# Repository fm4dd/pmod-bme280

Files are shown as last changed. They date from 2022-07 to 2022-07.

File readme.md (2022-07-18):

## BME280 PMOD

### Description

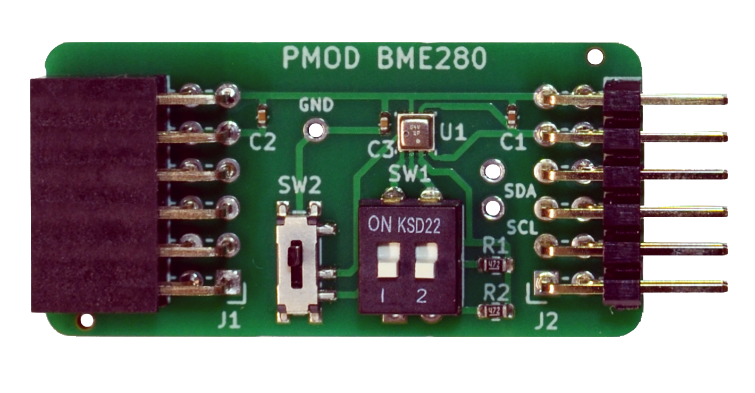
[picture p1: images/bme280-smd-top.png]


This PMOD connects the Bosch BME280 humidity, pressure and temperature sensor over I2C, using Digilent's PMOD interface type 6A per PMOD specification v1.3.1. The PMOD module can be chained to add additional I2C devices to the bus. The I2C pull-up resistors can be enabled/disabled using DIP switches, and switch 2 toggles the sensors I2C address between 0x76 and 0x77.

http://fpga.fm4dd.com/

This design is registered under the OSHWA Open Source Hardware Self-Certification:



### Schematic
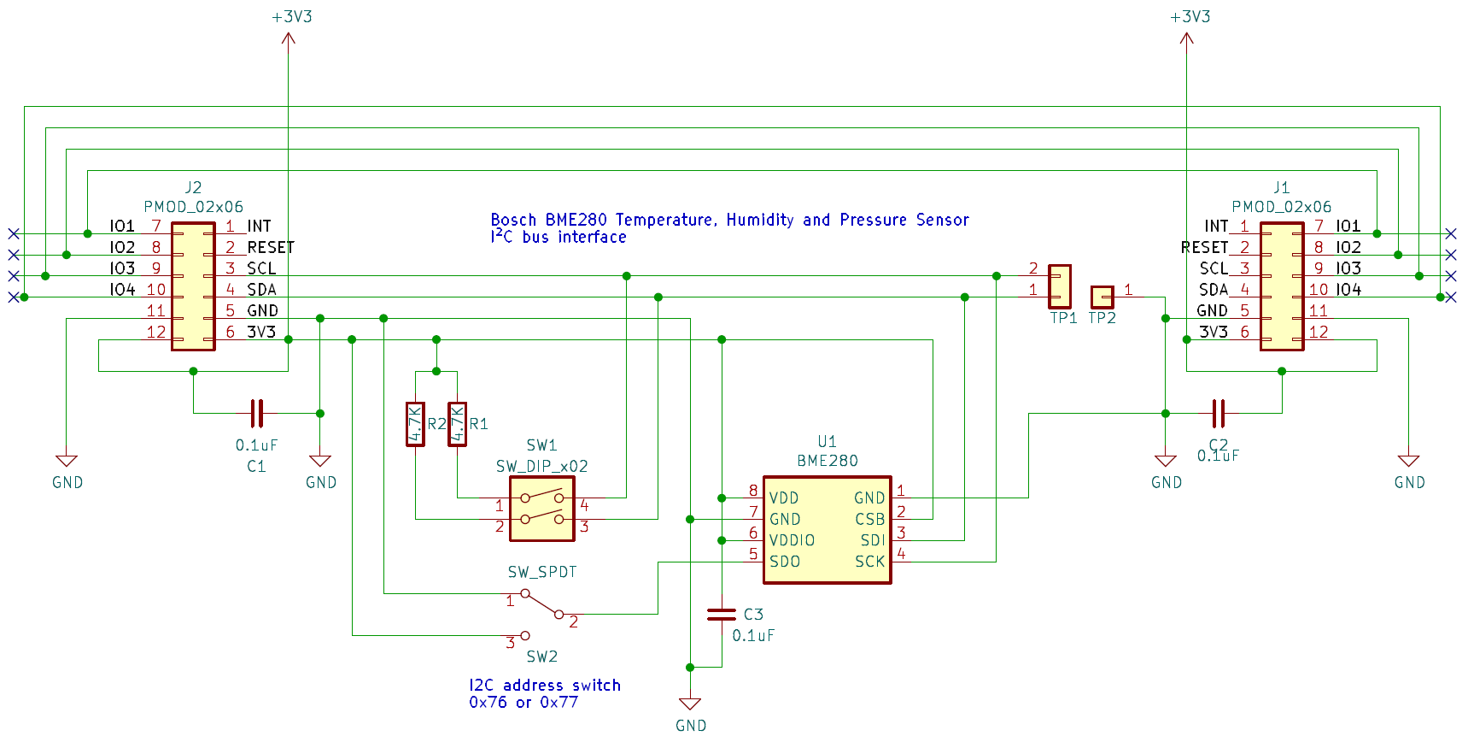
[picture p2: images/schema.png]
BME280 PMOD Schematics


### PCB Gerber
[BME280 PMOD Gerber V1.0](20220624-bme280-gerber-v10.zip)

### PMOD Interface Pin Assignments

Pin  |	Label |	Description   | Pin  |	Label |	Description
-----|--------|---------------|------|--------|---------------
1    |	-     |	Not connected |7     | -      | Not connected
2    |	-     |	Not connected |8     | -      | Not connected
3    |	SCL   |	I2C clock     |9     | -      | Not connected
4    |  SDA   | I2C data      |10    | -      | Not connected
5    |  GND   | ground        |11    | GND    | ground
6    |  3V3   | 3.3V          |12    | 3V3    | 3.3V

All pins are passed through from connector J1 to J2, allowing to chain multiple type 6/6A PMODs.

### Example Code

#### Linux

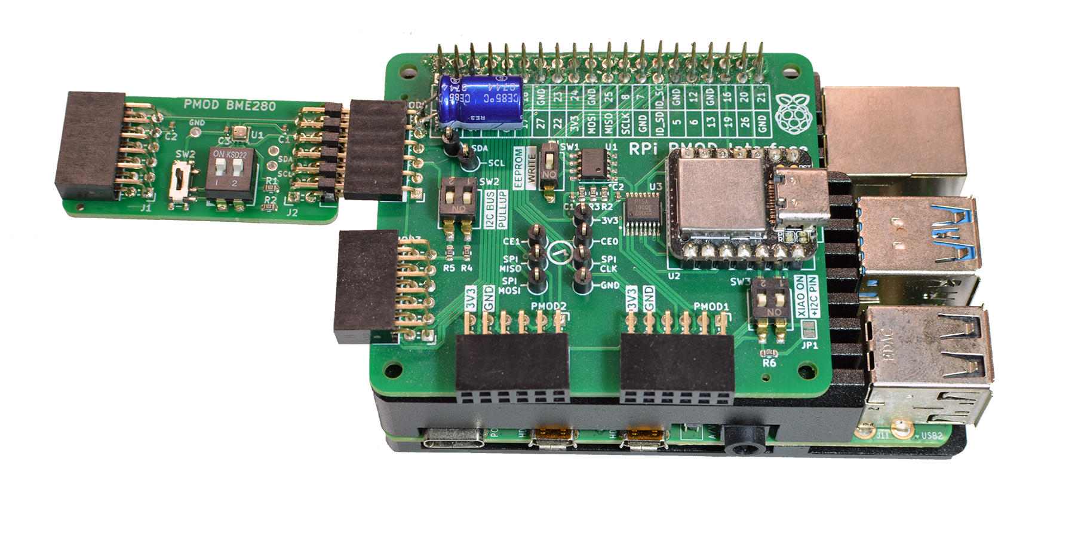
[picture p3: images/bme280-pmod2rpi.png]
BME280 PMOD on PMOD2RPI


Above shows the BME280 PMOD, connected to a [PMOD2RPI](https://github.com/fm4dd/pmod2rpi) interface board. When connected through the PMOD4 connector, the module can be controlled from the Raspberry Pi 4 Linux, running the [pi-bme280](https://github.com/fm4dd/pi-bme280) control program.

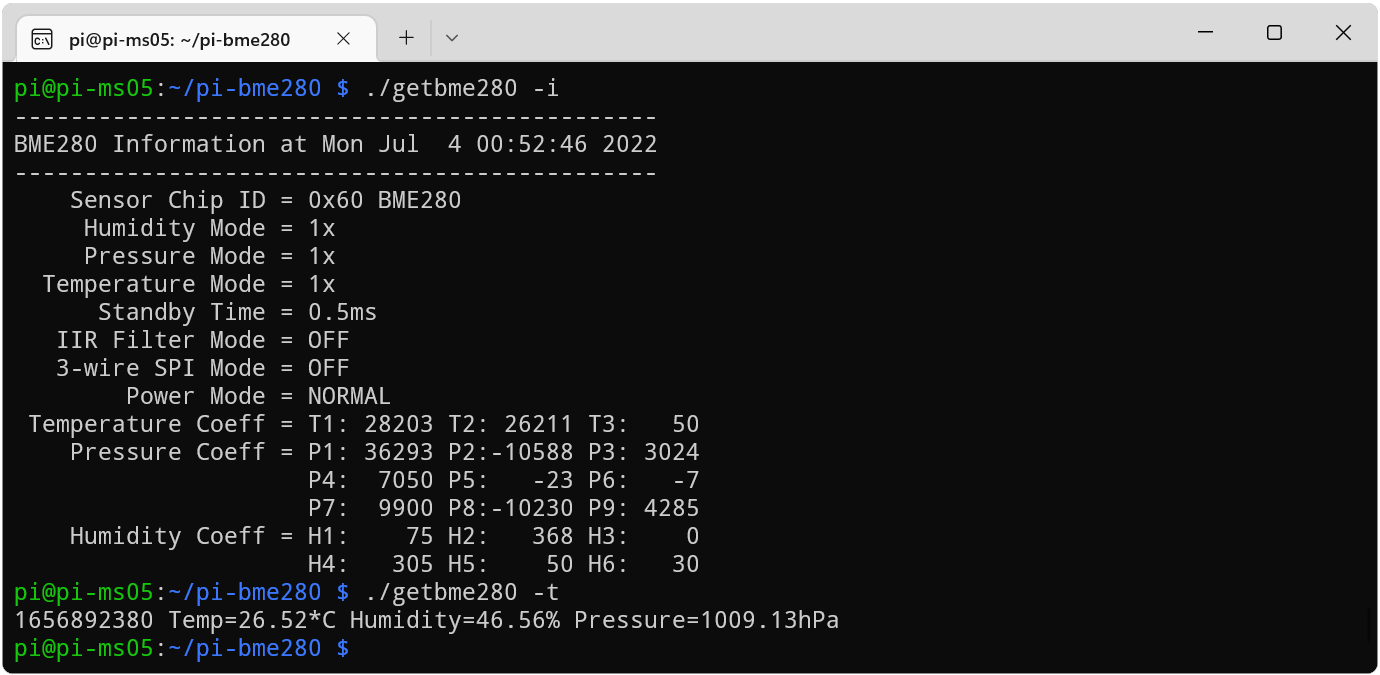
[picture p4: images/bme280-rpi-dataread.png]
BME280 PMOD Data Read


#### Arduino

Without any changes, we can run BME280 sample code such as the [BMx280_I2C](https://bitbucket.org/christandlg/bmx280mi/src/master/examples/BMx280_I2C/BMx280_I2C.ino) example program from the BMx280MI library provided by Gregor Christandl. The BME280 PMOD module is connected to the [PMOD2RPI](https://github.com/fm4dd/pmod2rpi) interface board. On port PMOD1, the module communicates over I2C with the onboard Seeedstudio XIAO Cortex-M0 MCU.

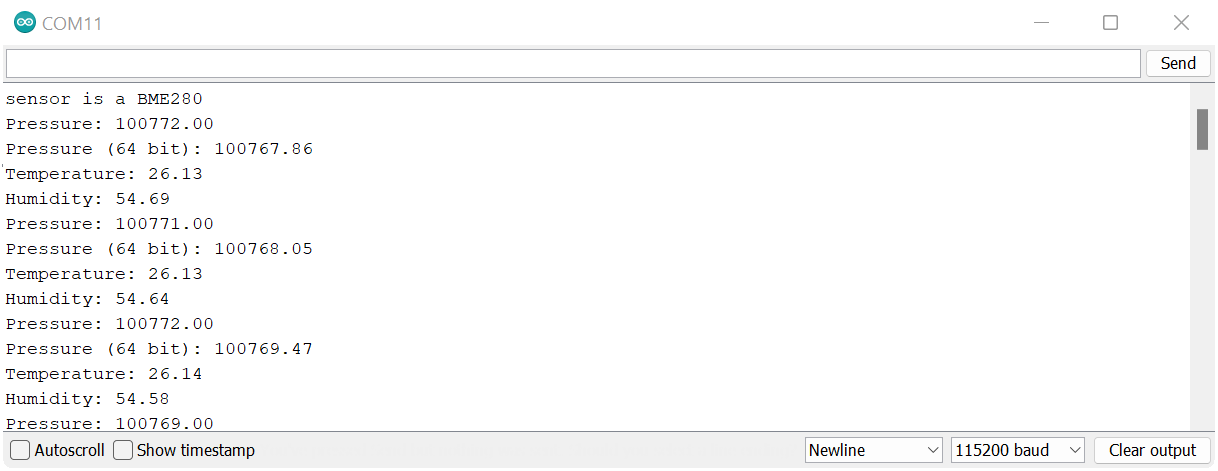
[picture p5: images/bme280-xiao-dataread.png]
BME280 PMOD Data Read


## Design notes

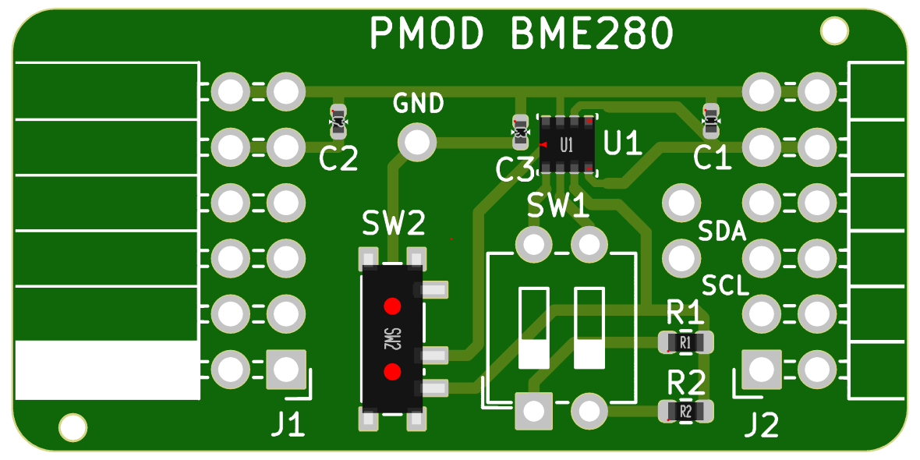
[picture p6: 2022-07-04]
images/bme280-smd-v10.png

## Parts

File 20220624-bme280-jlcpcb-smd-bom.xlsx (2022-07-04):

Comment | Designator | Footprint | LCSC Part #（optional）
BME280 | U1 | LGA-8_2.5x2.5x0.65P | C92489
SPDT | SW2 | Switch_SMD:SW_12mm | C397350
4.7K | R2,R1 | Resistor_SMD:R_0603_1608Metric
100nF | C3,C2,C1 | Capacitor_SMD:C_0402Metric

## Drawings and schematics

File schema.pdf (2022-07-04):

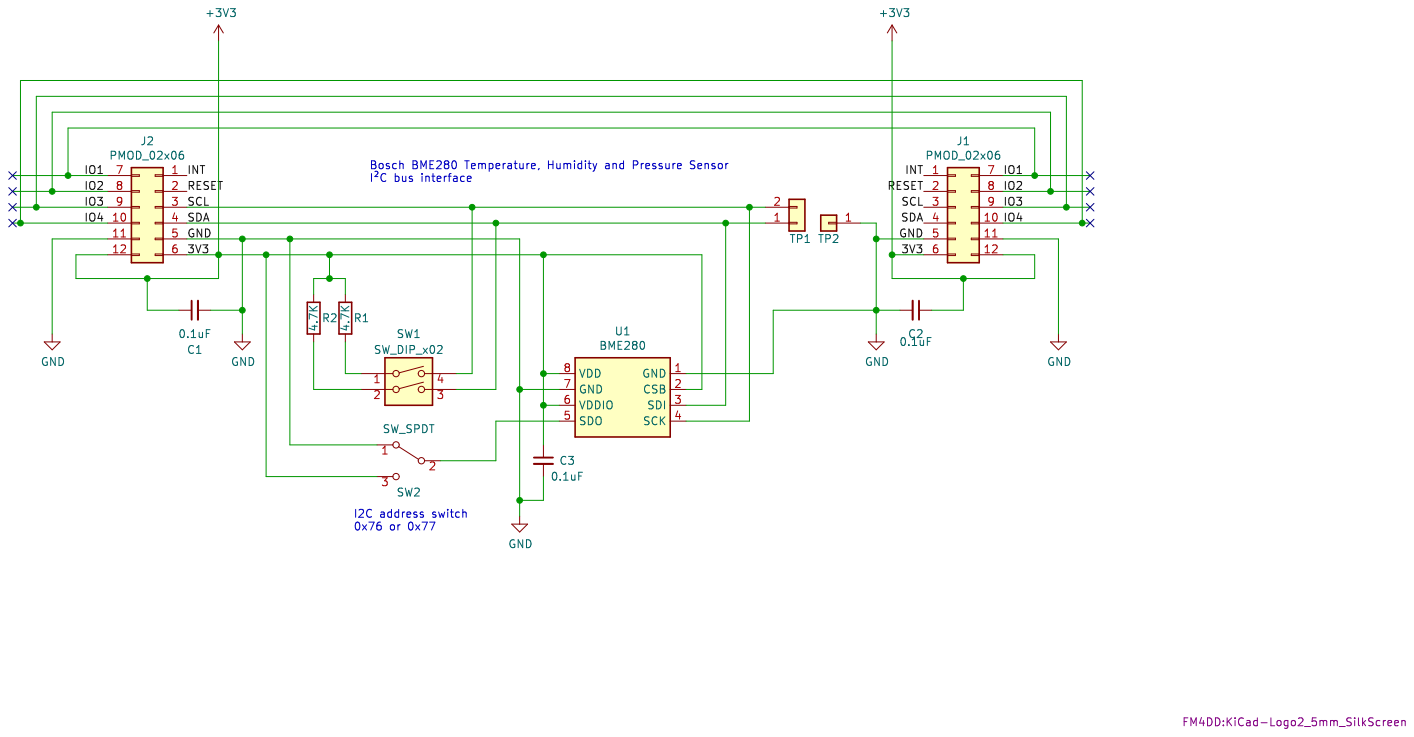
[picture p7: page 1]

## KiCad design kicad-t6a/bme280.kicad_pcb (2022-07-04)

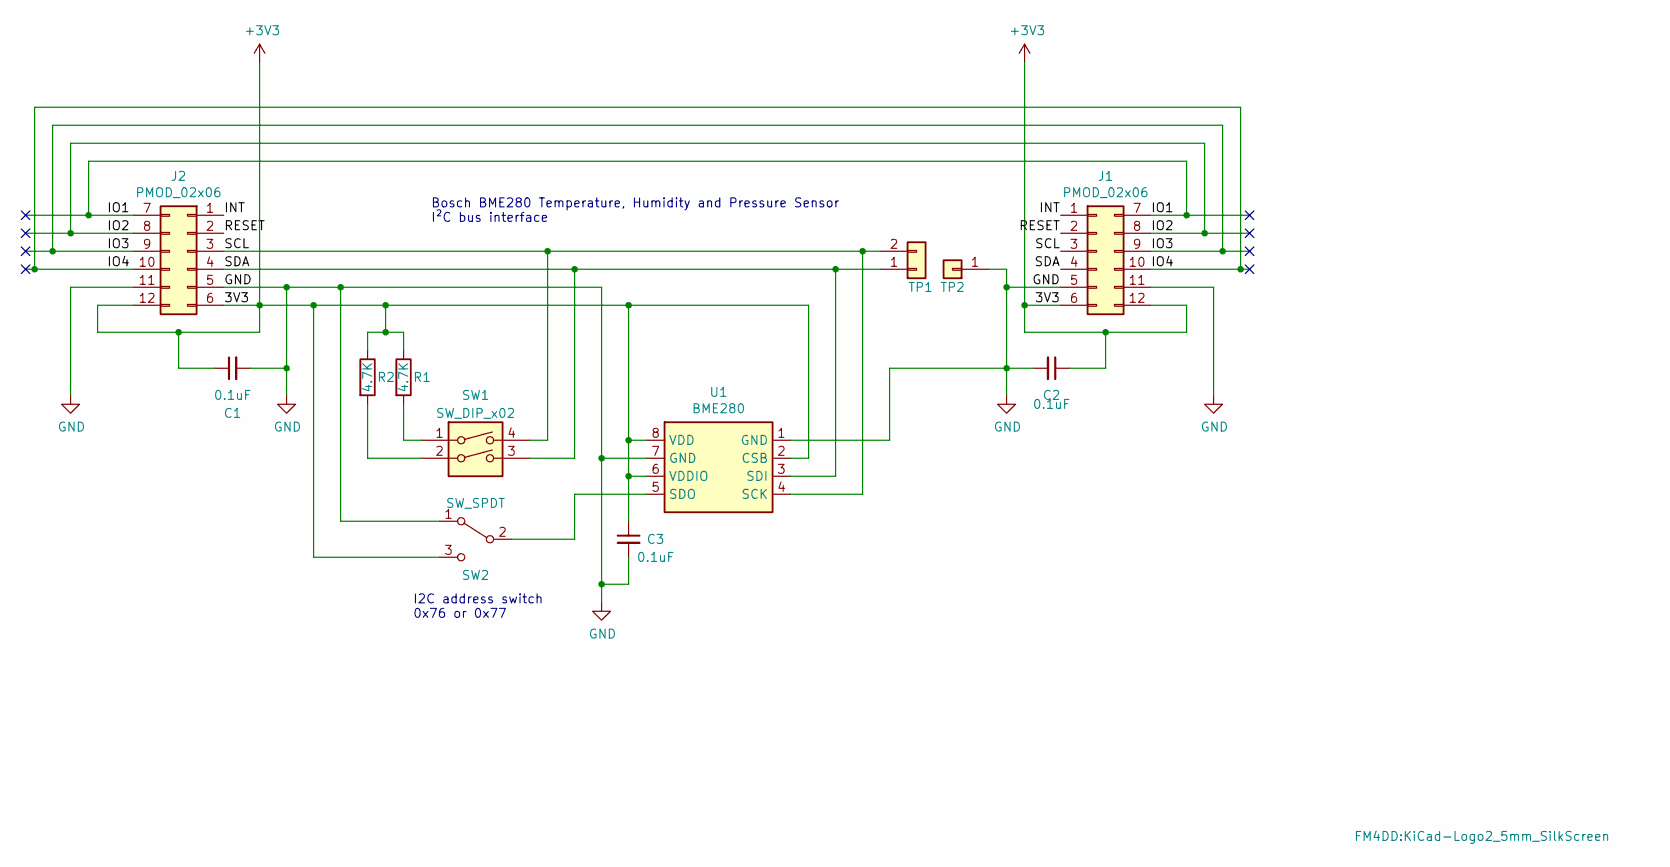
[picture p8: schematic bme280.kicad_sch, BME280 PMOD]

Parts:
C1, C2, C3: 0.1uF; C_0402_1005Metric
J1: PMOD_02x06; PMODPinSocket_2x06_P2.54mm_Horizontal
J2: PMOD_02x06; PMODHeader_2x06_P2.54mm_Horizontal
L1: Logo_KiCad_5mm; KiCad-Logo2_5mm_SilkScreen
R1, R2: 4.7K; R_0603_1608Metric
SW1: SW_DIP_x02; SW_DIP_SPSTx02_Slide_6.7x6.64mm_W7.62mm_P2.54mm_LowProfile
SW2: SW_SPDT; SW_SPDT_XKB-SS-3292S
TP1: Conn_01x02; Testpoint_PinHeader_1x02_P2.54mm_Vertical
TP2: TestPoint_Conn_01x01; TestPoint_PinHeader_1x01_P2.54mm_Vertical
U1: BME280; Bosch_LGA-8_2.5x2.5mm_P0.65mm_ClockwisePinNumbering

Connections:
+3V3: C1.1, C2.1, C3.1, J1.6, J1.12, J2.6, J2.12, R1.1, R2.1, SW2.3 (C), U1.2 (CSB), U1.6 (VDDIO), U1.8 (VDD)
/INT: J1.1, J2.1
/IO1: J1.7, J2.7
/IO2: J1.8, J2.8
/IO3: J1.9, J2.9
/IO4: J1.10, J2.10
/RESET: J1.2, J2.2
/SCL: J1.3, J2.3, SW1.4, TP1.2, U1.4 (SCK)
/SDA: J1.4, J2.4, SW1.3, TP1.1, U1.3 (SDI)
GND: C1.2, C2.2, C3.2, J1.5, J1.11, J2.5, J2.11, SW2.1 (A), TP2.1, U1.1 (GND), U1.7 (GND)
unnamed: R1.2, SW1.1
unnamed: R2.2, SW1.2
unnamed: SW2.2 (B), U1.5 (SDO)

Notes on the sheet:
I2C address switch 0x76 or 0x77
Bosch BME280 Temperature, Humidity and Pressure Sensor I²C bus interface

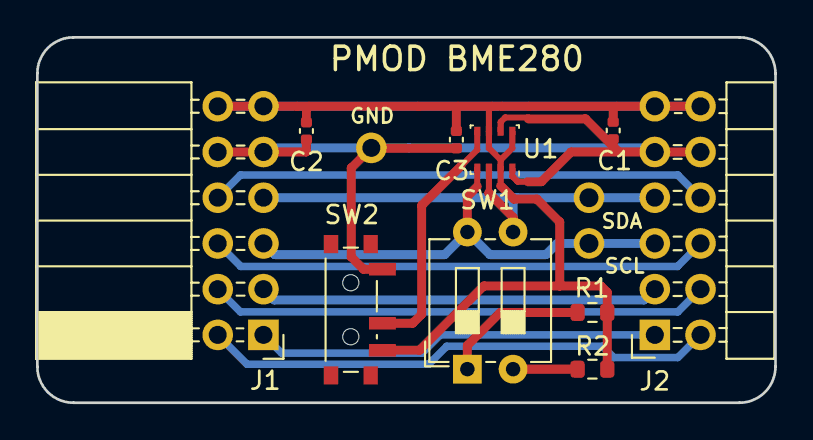
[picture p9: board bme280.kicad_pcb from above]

Board: 2 copper layers, 41.0 x 20.3 mm, 14 parts (1 on the bottom side), 13 nets.

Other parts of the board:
Ref**: JLCPCB_Order_Number_Placeholder

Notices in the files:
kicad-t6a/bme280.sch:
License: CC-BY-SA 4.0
